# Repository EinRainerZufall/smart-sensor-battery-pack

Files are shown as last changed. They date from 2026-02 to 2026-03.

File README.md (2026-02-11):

# Smart Sensor Battery Pack
This is the experimental battery charging PCB designed for my YouTube video. You can see the full build process, design theory, and assembly in the video below:

Watch the video (https://www.youtube.com/watch?v=-wEKOhVZ0NM)

### Please note: 
This board is currently missing a pull up resistor on the SCL/SDA lines - I will be adding this very soon. Software correction is possible using the XIAO pull-ups, and closing the FET early in the boot cycle. So using the board in its current form just makes the code a little more verbose. 

```
# Force GPIO18 LOW (Turns P-Channel MOSFET on)
# Set priority such that this runs before i2c initialises
esphome:
  on_boot:
    - priority: 1200
      then:
        - lambda: |-
            gpio_config_t io_conf = {};
            io_conf.pin_bit_mask = (1ULL<<18);
            io_conf.mode = GPIO_MODE_OUTPUT;
            io_conf.pull_up_en = GPIO_PULLUP_DISABLE;
            io_conf.pull_down_en = GPIO_PULLDOWN_DISABLE;
            io_conf.intr_type = GPIO_INTR_DISABLE;
            gpio_config(&io_conf);
            gpio_set_level(GPIO_NUM_18, 0);

# Software accessible pullups
i2c:
  sda_pullup_enabled: true
  scl_pullup_enabled: true

```

## ⚠️ Safety Warning
This board involves **Lithium-Ion battery charging**. 
*   This is an **experimental prototype** from a hobbyist. **I am not a professional engineer**. It has **not** been certified by safety agencies (UL, CE, etc.).
*   Lithium batteries can be dangerous if mishandled (risk of thermal runaway, fire, explosion, and serious injury).
*   **DO NOT leave this device unattended with a battery connected**
*   By using these files, you agree that you are solely responsible for verifying the safety of the circuit.

## License & Liability

### 1. Non-Commercial Use Only
This project is shared under the [Creative Commons Attribution-NonCommercial-ShareAlike 4.0 International](https://creativecommons.org/licenses/by-nc-sa/4.0/) license.
*  **You are free to:** Download, modify, and build this for personal use or learning.
*  **You may NOT:** Sell this board, use it in a product you sell, or use these files for any commercial purpose.
*  If you modify and share this design, you must share it under this same license.

### 2. No Liability (Disclaimer)
These files are provided "As Is" for educational purposes ONLY. I am sharing my personal project notes. **I accept no liability for any damage, injury, or loss** that occurs from the use or assembly of these files. Use them at your own risk.

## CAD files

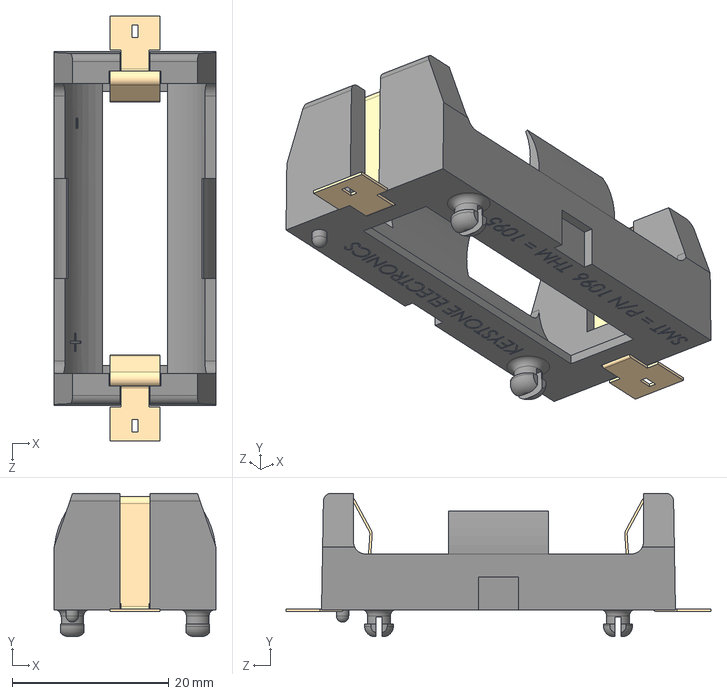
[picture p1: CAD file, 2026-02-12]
PCB/3d_models/1096.step
20.7 x 18.3 x 54.2 mm

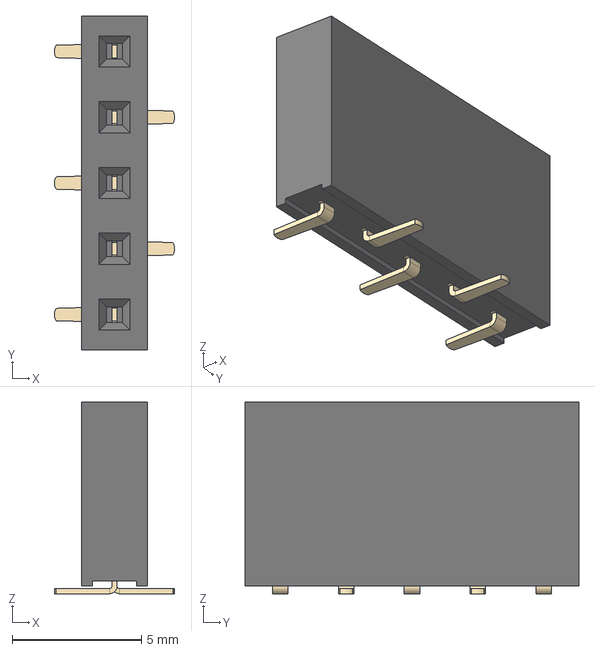
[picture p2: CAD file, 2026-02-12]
PCB/3d_models/PinSocket_1x05_P2.54mm_Vertical_SMD_Pin1Left.step
4.64 x 12.9 x 7.40 mm

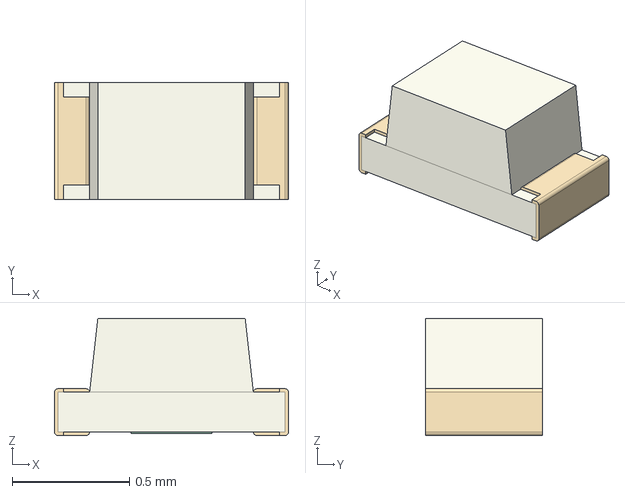
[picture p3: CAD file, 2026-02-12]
PCB/3d_models/LED_0402_1005Metric.step
1.00 x 0.5 x 0.5 mm

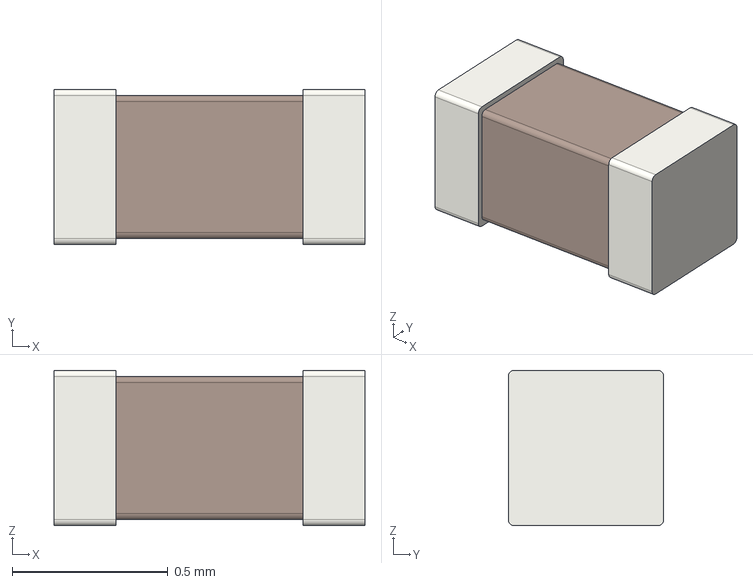
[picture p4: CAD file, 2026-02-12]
PCB/3d_models/C_0402_1005Metric.step
1.00 x 0.5 x 0.5 mm

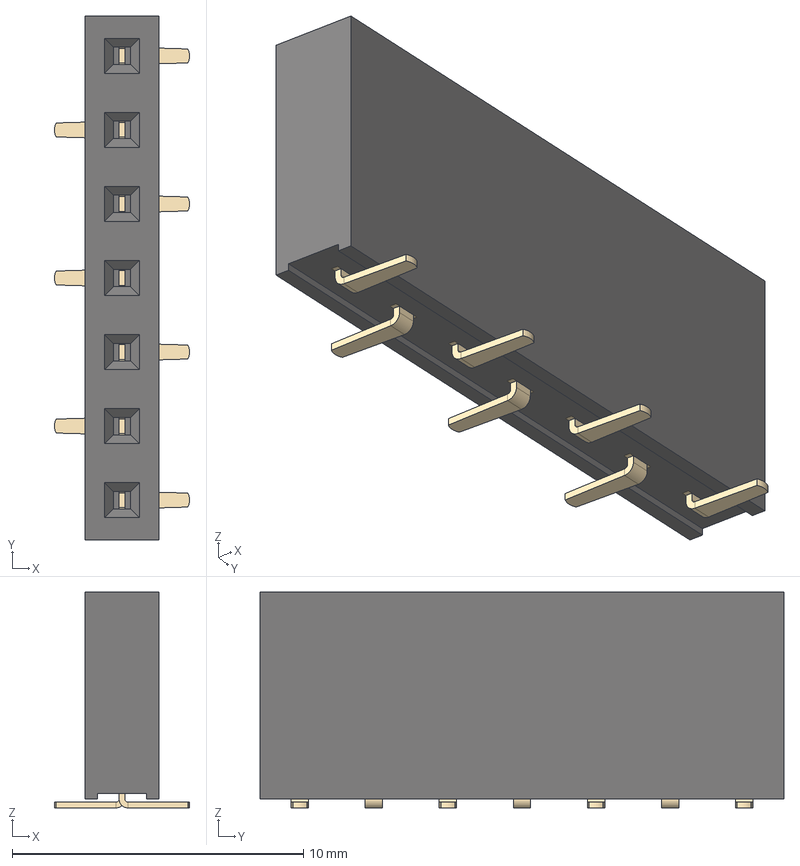
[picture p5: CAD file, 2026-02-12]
PCB/3d_models/PinSocket_1x07_P2.54mm_Vertical_SMD_Pin1Right.step
4.64 x 18.0 x 7.40 mm

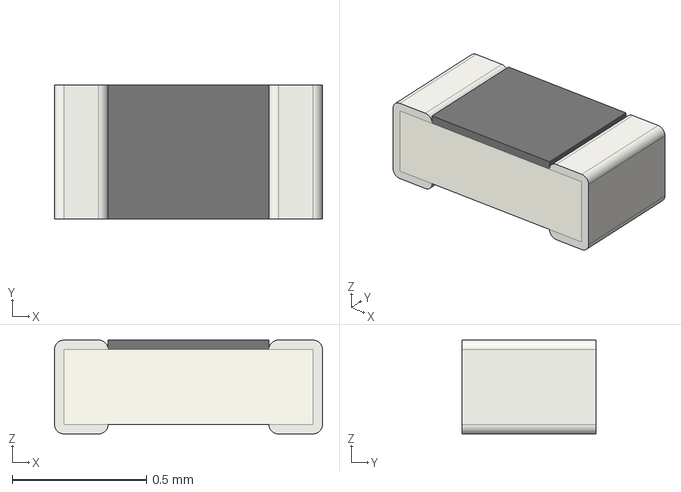
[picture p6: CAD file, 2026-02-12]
PCB/3d_models/R_0402_1005Metric.step
1.00 x 0.5 x 0.35 mm

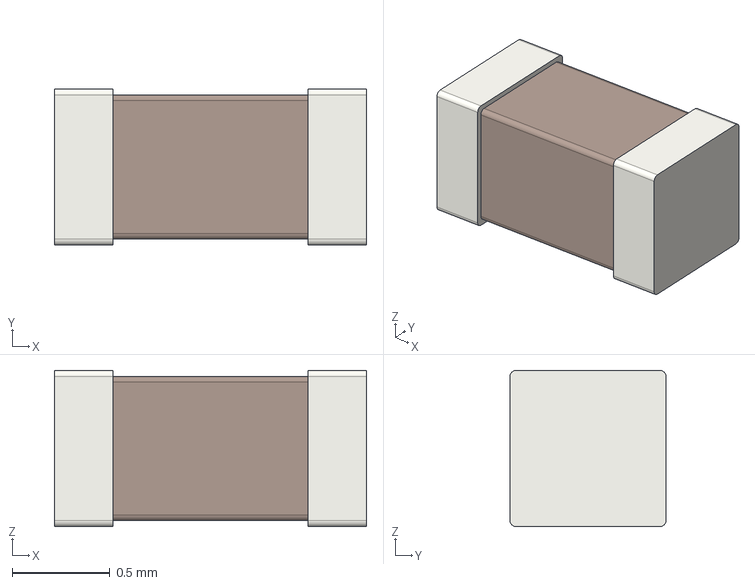
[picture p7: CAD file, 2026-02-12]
PCB/3d_models/C_0603_1608Metric.step
1.60 x 0.8 x 0.8 mm

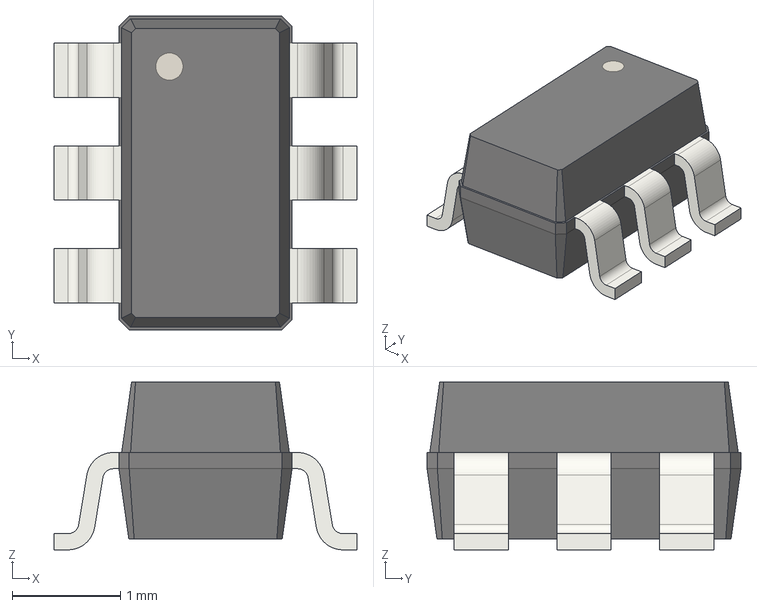
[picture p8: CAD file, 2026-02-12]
PCB/3d_models/SOT-23-6.step
2.80 x 2.90 x 1.55 mm

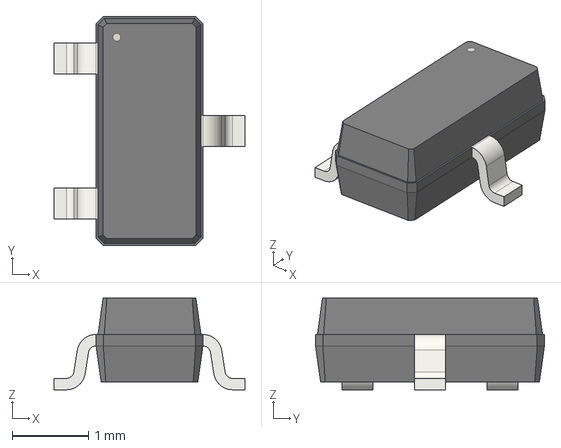
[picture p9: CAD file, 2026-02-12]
PCB/3d_models/SOT-23.step
2.50 x 3.00 x 1.20 mm

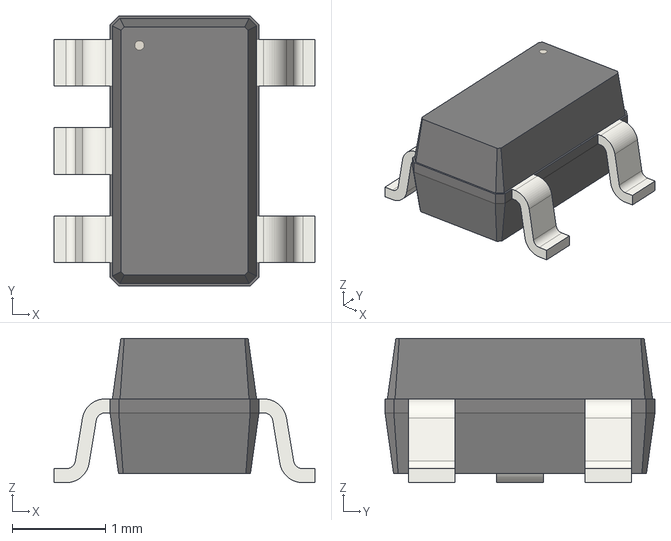
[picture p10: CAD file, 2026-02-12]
PCB/3d_models/SOT-23-5.step
2.80 x 2.90 x 1.55 mm

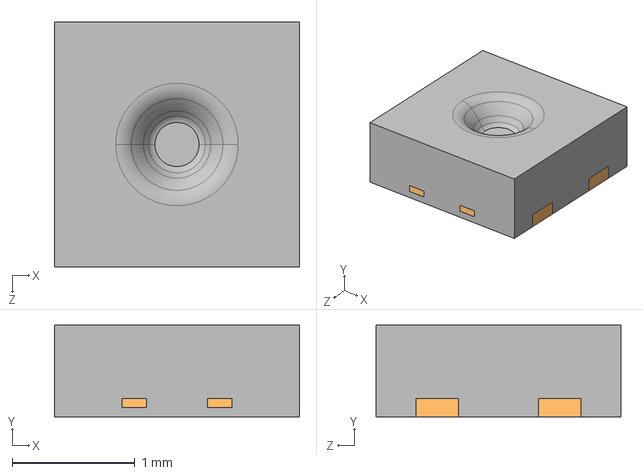
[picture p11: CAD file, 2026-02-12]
PCB/3d_models/SHTC3.step
2.00 x 0.75 x 2.00 mm

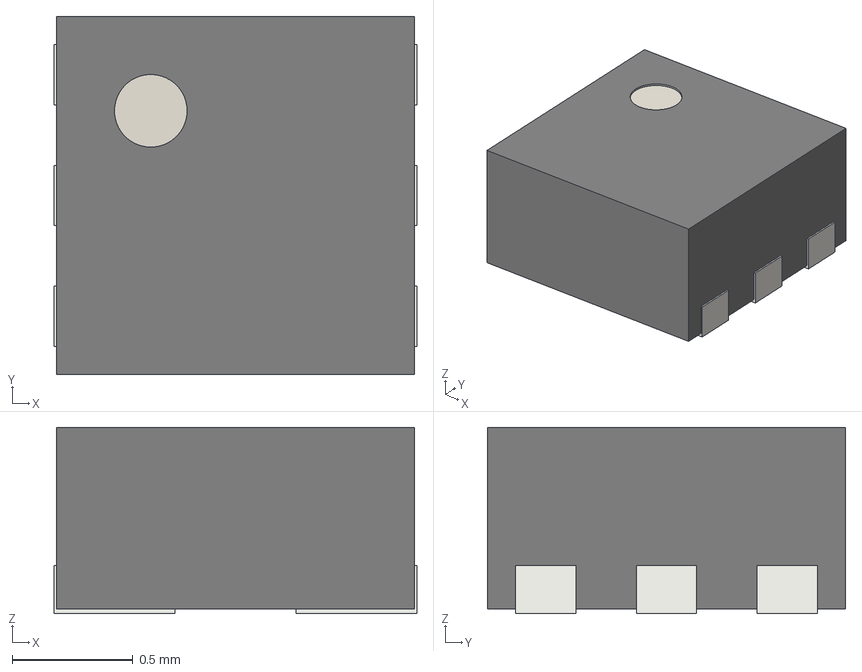
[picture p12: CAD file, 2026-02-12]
PCB/3d_models/WSON-6_1.5x1.5mm_P0.5mm.step
1.50 x 1.48 x 0.77 mm

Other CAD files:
PCB/3d_models/PinSocket_1x07_P2.54mm_Vertical_SMD_Pin1Left.step

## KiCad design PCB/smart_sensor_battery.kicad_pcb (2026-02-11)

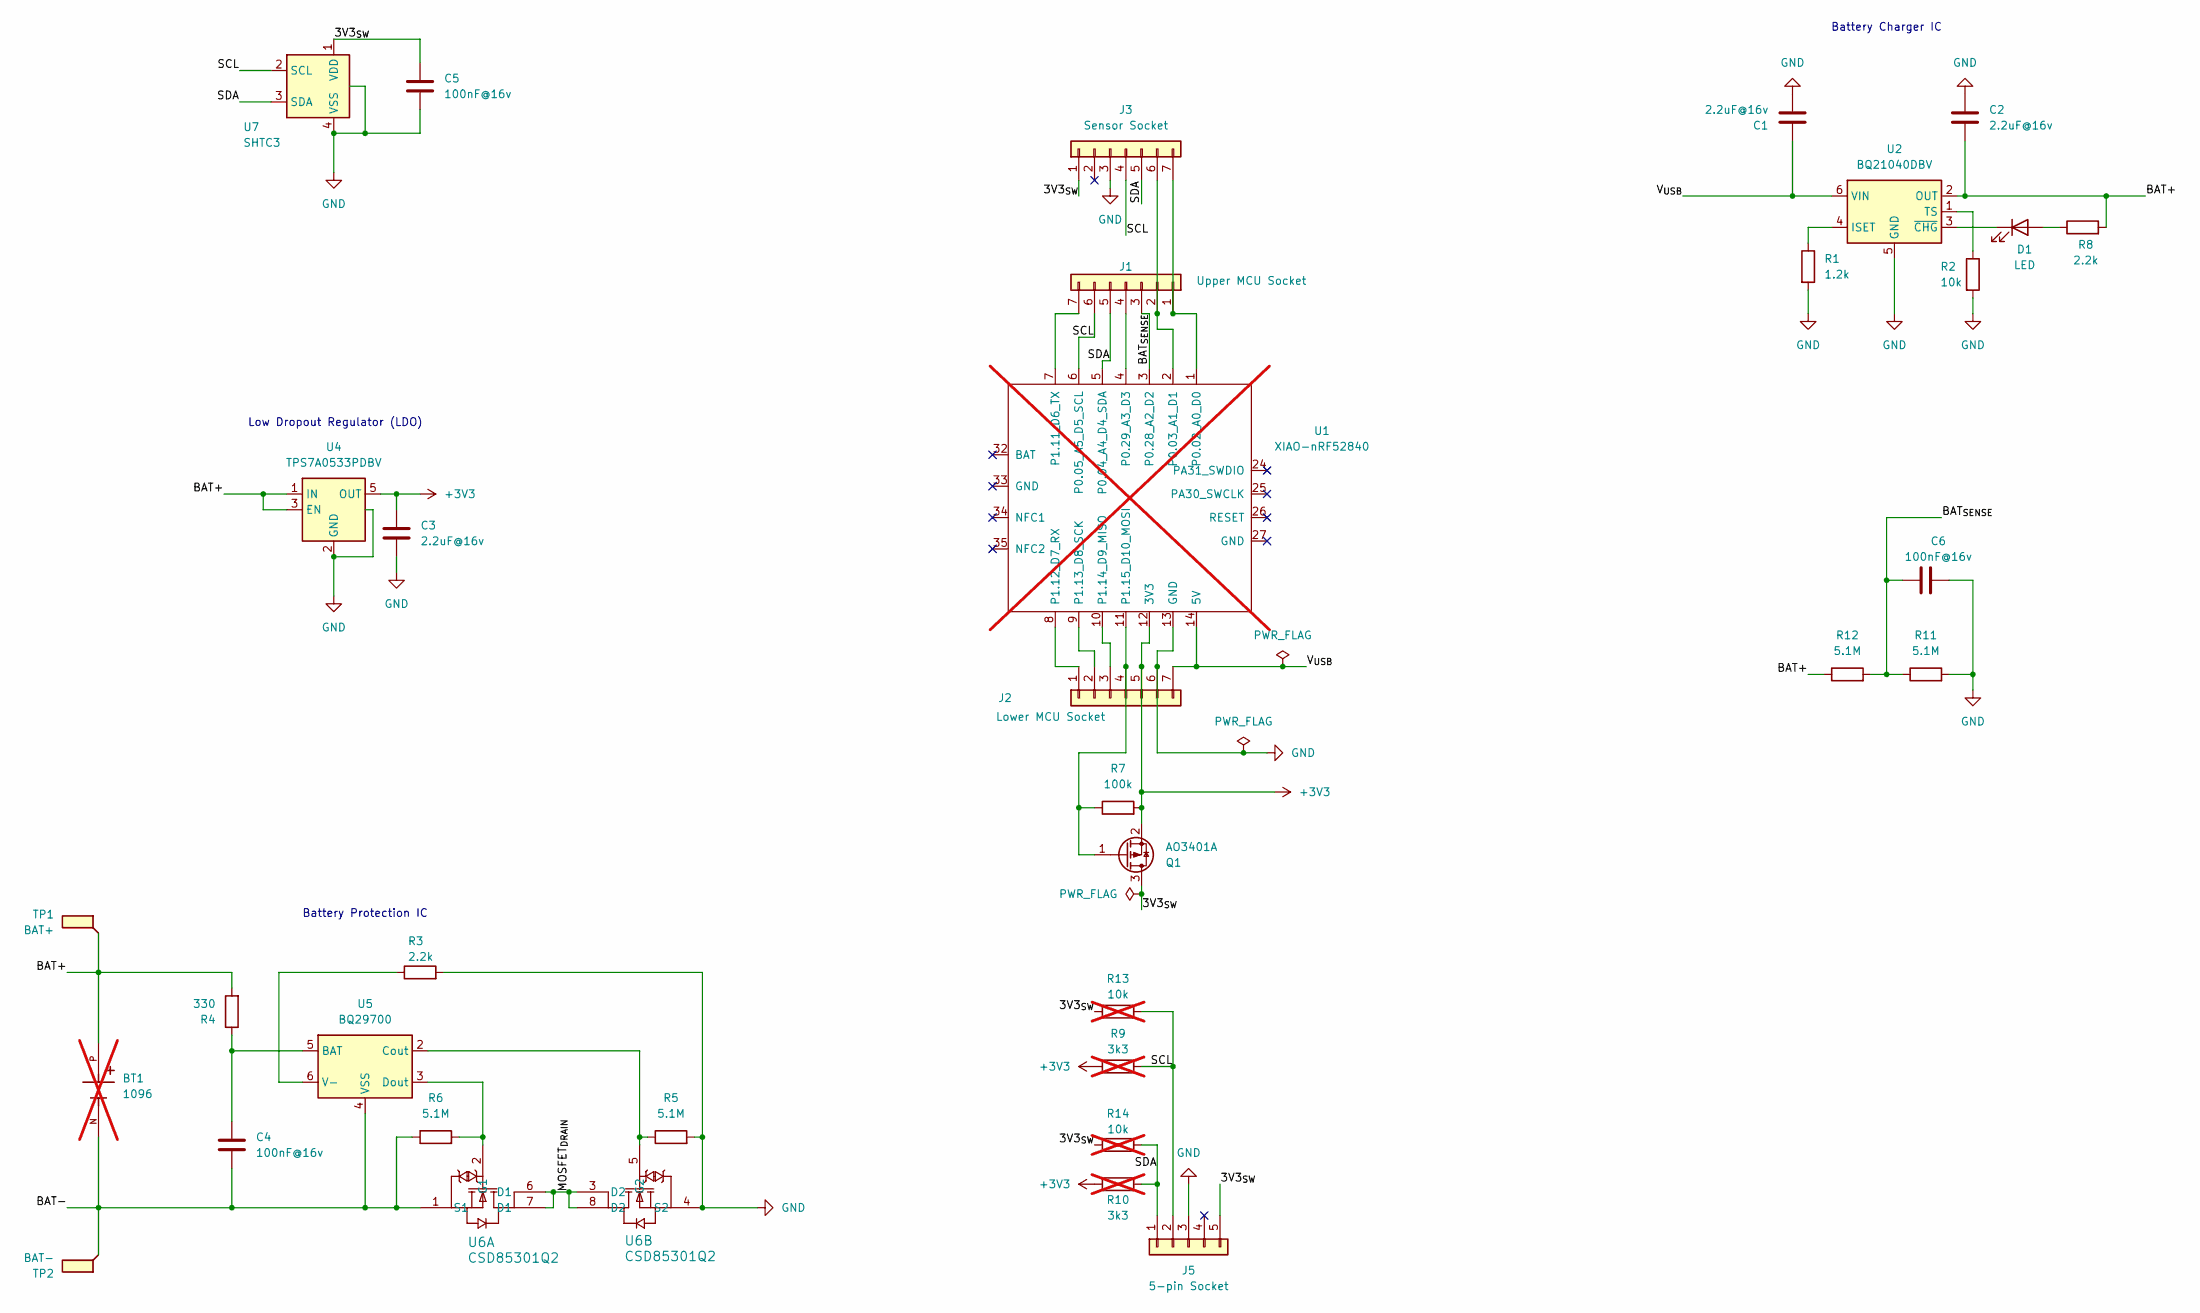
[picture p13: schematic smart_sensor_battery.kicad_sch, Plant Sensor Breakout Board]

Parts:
BT1: 1096; BAT_1096; PARTREV A; not fitted
C1, C2, C3: 2.2uF@16v; C_0603_1608Metric; LCSC C23630
C4, C5, C6: 100nF@16v; C_0402_1005Metric; LCSC C1525
D1: LED; LED_0402_1005Metric; LCSC C74339
J1: Upper MCU Socket; PinSocket_1x07_P2.54mm_Vertical_SMD_Pin1Left; LCSC C42379199
J2: Lower MCU Socket; PinSocket_1x07_P2.54mm_Vertical_SMD_Pin1Right; LCSC C42379199
J3: Sensor Socket; PinSocket_1x07_P2.54mm_Vertical_SMD_Pin1Right; LCSC C42379199
J5: 5-pin Socket; PinSocket_1x05_P2.54mm_Vertical_SMD_Pin1Left; LCSC C42379198
Q1: AO3401A; SOT-23; LCSC C15127
R1: 1.2k; R_0402_1005Metric; LCSC C25862
R2: 10k; R_0402_1005Metric; LCSC C25744
R3, R8: 2.2k; R_0402_1005Metric; LCSC C25879
R4: 330; R_0402_1005Metric; LCSC C25104
R5, R6, R11, R12: 5.1M; R_0402_1005Metric; LCSC C26092
R7: 100k; R_0402_1005Metric; LCSC C25530
R9, R10: 3k3; R_0402_1005Metric; LCSC C60490; not fitted
R13, R14: 10k; R_0402_1005Metric; LCSC C25744; not fitted
TP1: BAT+; TestPoint_Pad_4.0x4.0mm
TP2: BAT-; TestPoint_Pad_4.0x4.0mm
U1: XIAO-nRF52840; XIAO-nRF52840-SMD; not fitted
U2: BQ21040DBV; SOT-23-6; LCSC C202311
U4: TPS7A0533PDBV; SOT-23-5; LCSC C493453
U5: BQ29700; WSON-6_1.5x1.5mm_P0.5mm; LCSC C183096
U6: CSD85301Q2; LCSC C544396
U7: SHTC3; Sensirion_DFN-4-1EP_2x2mm_P1mm_EP0.7x1.6mm

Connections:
+3V3: C3.1, J2.5, Q1.2 (S), R7.2, R9.1, R10.1, U1.12 (3V3), U4.5 (OUT)
/3V3_{SW}: C5.1, J3.1, J5.5, Q1.3 (D), R13.1, R14.1, U7.1 (VDD)
/BAT+: BT1.P, C2.1, R4.2, R8.2, R12.1, TP1.1, U2.2 (OUT), U4.1 (IN), U4.3 (EN)
/BAT-: BT1.N, C4.2, R6.1, TP2.1, U5.4 (VSS), U6.1 (S1)
/BAT_{SENSE}: C6.1, J1.3, R11.1, R12.2, U1.3 (P0.28_A2_D2)
/MOSFET_{DRAIN}: U6.3 (D2), U6.6 (D1), U6.7 (D1), U6.8 (D2)
/SCL: J1.6, J3.4, J5.2, R9.2, R13.2, U1.6 (P0.05_A5_D5_SCL), U7.2 (SCL)
/SDA: J1.5, J3.5, J5.1, R10.2, R14.2, U1.5 (P0.04_A4_D4_SDA), U7.3 (SDA)
/V_{USB}: C1.1, J2.7, U1.14 (5V), U2.6 (VIN)
GND: C1.2, C2.2, C3.2, C5.2, C6.2, J2.6, J3.3, J5.3, R1.2, R2.2, R3.2, R5.2, R11.2, U1.13 (GND), U2.5 (GND), U4.2 (GND), U4.4 (NC_(GND)), U6.4 (S2), U7.4 (VSS), U7.5 (GND_(centre_pad))
unnamed: D1.2 (A), R8.1
unnamed: D1.1 (K), U2.3 (~CHG)
unnamed: J1.1, J3.7, U1.1 (P0.02_A0_D0)
unnamed: J1.2, J3.6, U1.2 (P0.03_A1_D1)
unnamed: J1.4, U1.4 (P0.29_A3_D3)
unnamed: J1.7, U1.7 (P1.11_D6_TX)
unnamed: J2.1, U1.8 (P1.12_D7_RX)
unnamed: J2.2, U1.9 (P1.13_D8_SCK)
unnamed: J2.3, U1.10 (P1.14_D9_MISO)
unnamed: J2.4, Q1.1 (G), R7.1, U1.11 (P1.15_D10_MOSI)
unnamed: R1.1, U2.4 (ISET)
unnamed: R2.1, U2.1 (TS)
unnamed: C4.1, R4.1, U5.5 (BAT)
unnamed: R5.1, U5.2 (Cout), U6.5 (G2)
unnamed: R6.2, U5.3 (Dout), U6.2 (G1)
unnamed: R3.1, U5.6 (V-)

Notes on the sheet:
Battery Charger IC
Low Dropout Regulator (LDO)
Battery Protection IC

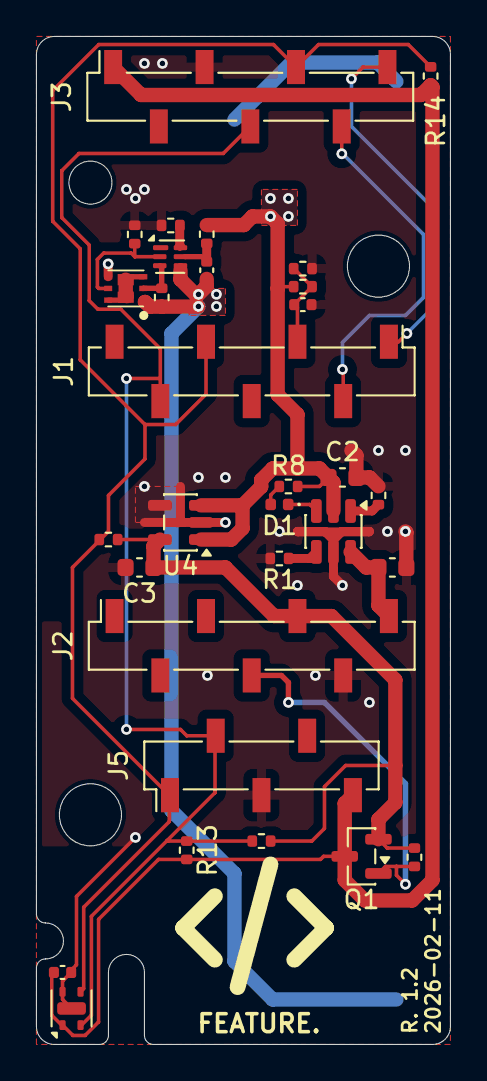
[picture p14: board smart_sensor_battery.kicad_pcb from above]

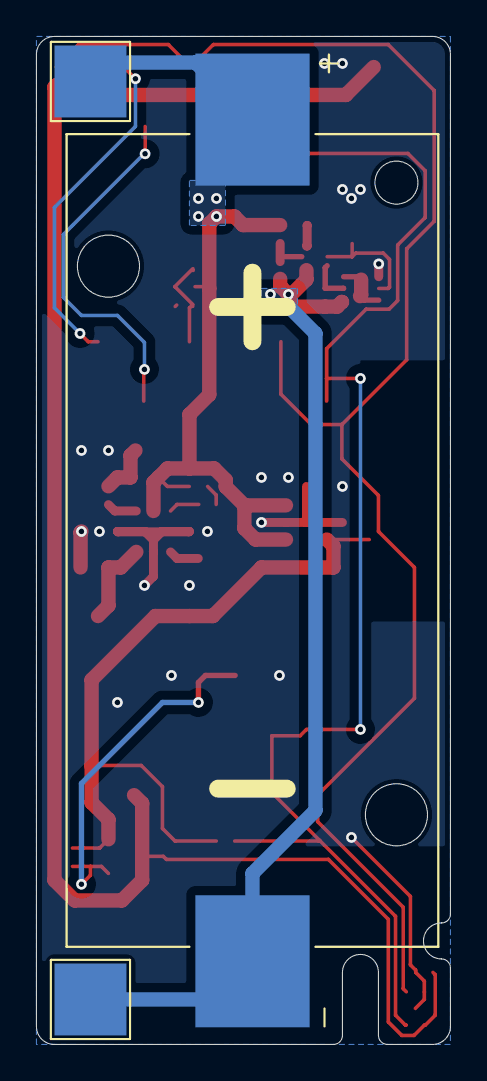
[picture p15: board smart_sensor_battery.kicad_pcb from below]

Board: 2 copper layers, 23.0 x 56.0 mm, 34 parts (3 on the bottom side), 21 nets.

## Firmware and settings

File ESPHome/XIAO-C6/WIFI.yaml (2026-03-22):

esphome:
  name: esp32-dev
  friendly_name: ESP32 Dev Board
  name_add_mac_suffix: True
  on_boot: 
    # Force GPIO18 LOW (Turns P-Channel MOSFET on)
    # Set priority such that this runs before i2c initialises
    - priority: 1200
      then:
        - lambda: |-
            gpio_config_t io_conf = {};
            io_conf.pin_bit_mask = (1ULL<<18);
            io_conf.mode = GPIO_MODE_OUTPUT;
            io_conf.pull_up_en = GPIO_PULLUP_DISABLE;
            io_conf.pull_down_en = GPIO_PULLDOWN_DISABLE;
            io_conf.intr_type = GPIO_INTR_DISABLE;
            gpio_config(&io_conf);
            gpio_set_level(GPIO_NUM_18, 0);

esp32:
  board: seeed_xiao_esp32c6
  framework:
    type: esp-idf

globals:
  - id: shtcx_done
    type: bool
    initial_value: "false"
  - id: bat_level_done
    type: bool
    initial_value: "false"
  - id: soil_done
    type: bool
    initial_value: "false"

external_components:
  - source:
      type: local
      path: .
    components: [ stemma_soil_sensor ]

deep_sleep:
  run_duration: 60s
  sleep_duration: 0.5min
  id: deep_sleep_ctrl

# Enable logging
logger:
  level: INFO

# Enable Home Assistant API
api:

#ota:
#  - platform: esphome

wifi:
  ssid: !secret wifi_ssid
  password: !secret wifi_password
  fast_connect: True
#  manual_ip: 
#    gateway: 192.168.0.1
#    subnet: 255.255.255.0
#    static_ip: 192.168.0.107

i2c:
  scl: GPIO23
  sda: GPIO22

sensor:
  - platform: shtcx
    id: shtcx_sensor
    update_interval: 10s
    temperature: 
      name: Temperatur
    humidity: 
      name: Luftfeuchte
      on_value: 
        then:
          - globals.set: 
              id: shtcx_done
              value: "true"
          - script.execute: check_all_done
  - platform: adc
    pin: GPIO2
    device_class: voltage
    name: Batteriespannung
    id: battery_voltage
    attenuation: 12db
    update_interval: 1s
    accuracy_decimals: 2
    entity_category: diagnostic
    filters: 
      - multiply: 2.0
      - median: 
          window_size: 5
          send_every: 5
          send_first_at: 3
    on_value: 
      then:
        - component.update: battery_level
  - platform: template
    name: Batterie
    id: battery_level
    device_class: battery
    unit_of_measurement: "%"
    lambda: "return id(battery_voltage).state;"
    update_interval: never
    accuracy_decimals: 0
    entity_category: diagnostic
    filters:
      - calibrate_polynomial: 
          degree: 3
          datapoints: 
            - 2.50 -> 0
            - 3.00 -> 2
            - 3.20 -> 7
            - 3.40 -> 20
            - 3.60 -> 45
            - 3.70 -> 58
            - 3.80 -> 70
            - 3.90 -> 80
            - 4.00 -> 88
            - 4.10 -> 95
            - 4.20 -> 100
      - clamp: 
          min_value: 0
          max_value: 100
    on_value: 
      then:
        - globals.set: 
            id: bat_level_done
            value: "true"
        - script.execute: check_all_done
  - platform: stemma_soil_sensor
    temperature:
      name: Bodentemperatur
    moisture:
      name: Bodenfeuchtigkeit
      unit_of_measurement: "%"
      filters:
        - calibrate_linear:
            - 200 -> 0    # Dry
            - 2000 -> 100  # Wet
        - lambda: |-
            if (x < 0.0) return 0.0;
            if (x > 100.0) return 100.0;
            return x;
      on_value: 
        then:
          - globals.set: 
              id: soil_done
              value: "true"
          - script.execute: check_all_done
    update_interval: 10s

script:
  - id: check_all_done
    then: 
      - logger.log: "Script: check_all_done"
      - if: 
          condition: 
            - all: 
                - lambda: "return id(shtcx_done);"
                - lambda: "return id(bat_level_done);"
                - lambda: "return id(soil_done);"
          then: 
            - deep_sleep.enter: deep_sleep_ctrl

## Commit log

2026-02-10 update to version 1.2
    [BMS.kicad_sch, smart_sensor_battery.kicad_pcb, smart_sensor_battery.kicad_sch]
2026-02-11 update to version 1.2b
    [smart_sensor_battery.kicad_pcb, smart_sensor_battery.kicad_sch]
2026-02-12 move PCB files to a seperate folder
    update .gitignore
    [1096.step, C_0402_1005Metric.step, C_0603_1608Metric.step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]
2026-03-22 update PCB
2026-03-22 add custom component for soil sensor
2026-03-22 add measurement of the power consumption
    [ppk_wifi_no_static.csv, ppk_wifi_static.csv]

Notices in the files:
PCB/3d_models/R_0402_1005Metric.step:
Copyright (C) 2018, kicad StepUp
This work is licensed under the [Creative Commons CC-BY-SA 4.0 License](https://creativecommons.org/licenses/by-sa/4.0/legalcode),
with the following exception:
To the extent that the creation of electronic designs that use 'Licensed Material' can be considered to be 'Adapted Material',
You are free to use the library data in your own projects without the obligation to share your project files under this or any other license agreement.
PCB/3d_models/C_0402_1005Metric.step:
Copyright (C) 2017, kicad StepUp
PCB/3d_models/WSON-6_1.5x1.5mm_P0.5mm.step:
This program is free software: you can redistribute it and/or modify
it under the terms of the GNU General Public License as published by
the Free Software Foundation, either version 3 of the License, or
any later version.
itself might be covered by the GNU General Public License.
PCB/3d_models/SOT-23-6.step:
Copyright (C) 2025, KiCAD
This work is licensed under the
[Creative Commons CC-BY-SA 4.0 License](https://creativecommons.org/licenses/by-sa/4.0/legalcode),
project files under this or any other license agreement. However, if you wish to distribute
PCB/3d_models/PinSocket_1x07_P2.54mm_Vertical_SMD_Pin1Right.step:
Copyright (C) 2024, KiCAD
